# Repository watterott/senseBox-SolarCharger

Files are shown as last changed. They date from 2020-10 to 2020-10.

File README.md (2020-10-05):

# senseBox SolarCharger
SolarCharger extension for the senseBox MCU

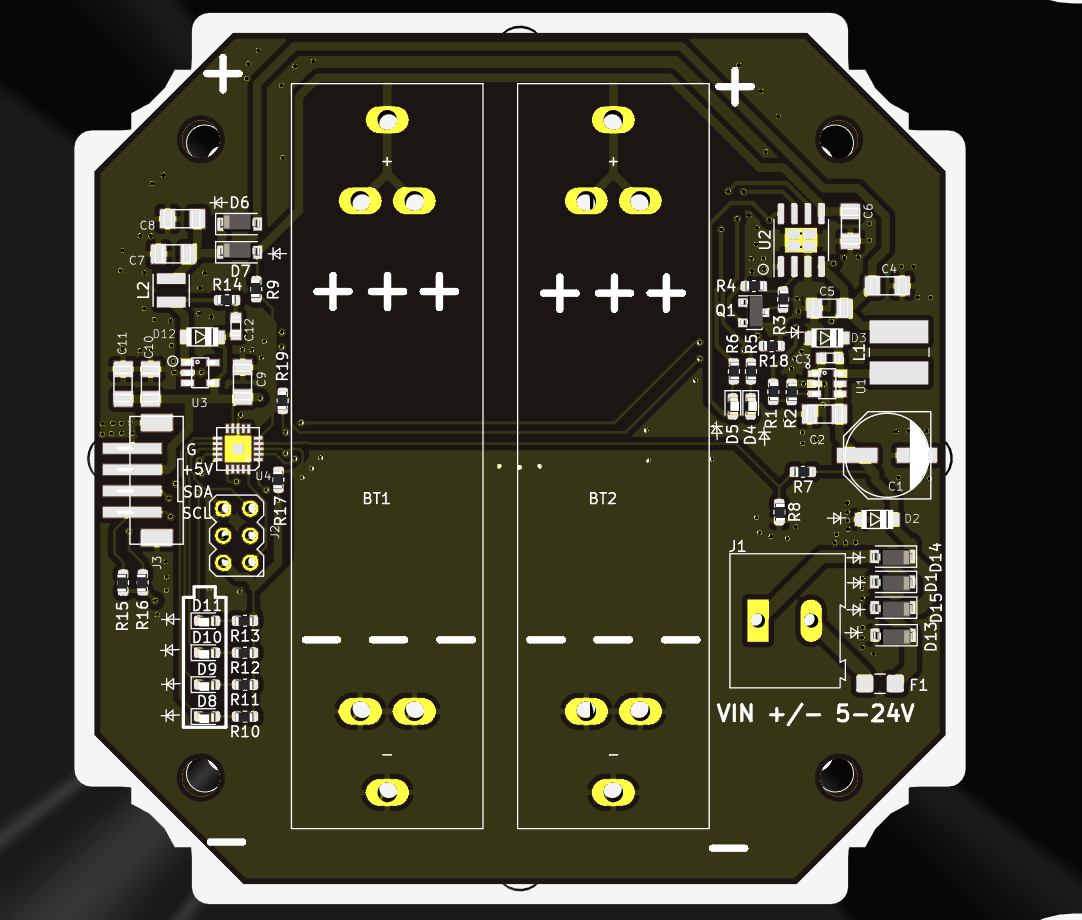
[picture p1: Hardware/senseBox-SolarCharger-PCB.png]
senseBox SolarCharger


* senseBox SolarCharger for up to 2x 18650 LiPo batteries
* 7-24V Solar input voltage
* Open-Source and released under the [Creative Commons Attribution Share-Alike License](https://creativecommons.org/licenses/by-sa/4.0/).
* **[Documentation on learn.watterott.com](https://learn.watterott.com)**

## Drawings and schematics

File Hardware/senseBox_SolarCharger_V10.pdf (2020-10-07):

10k | C10
100n | R19

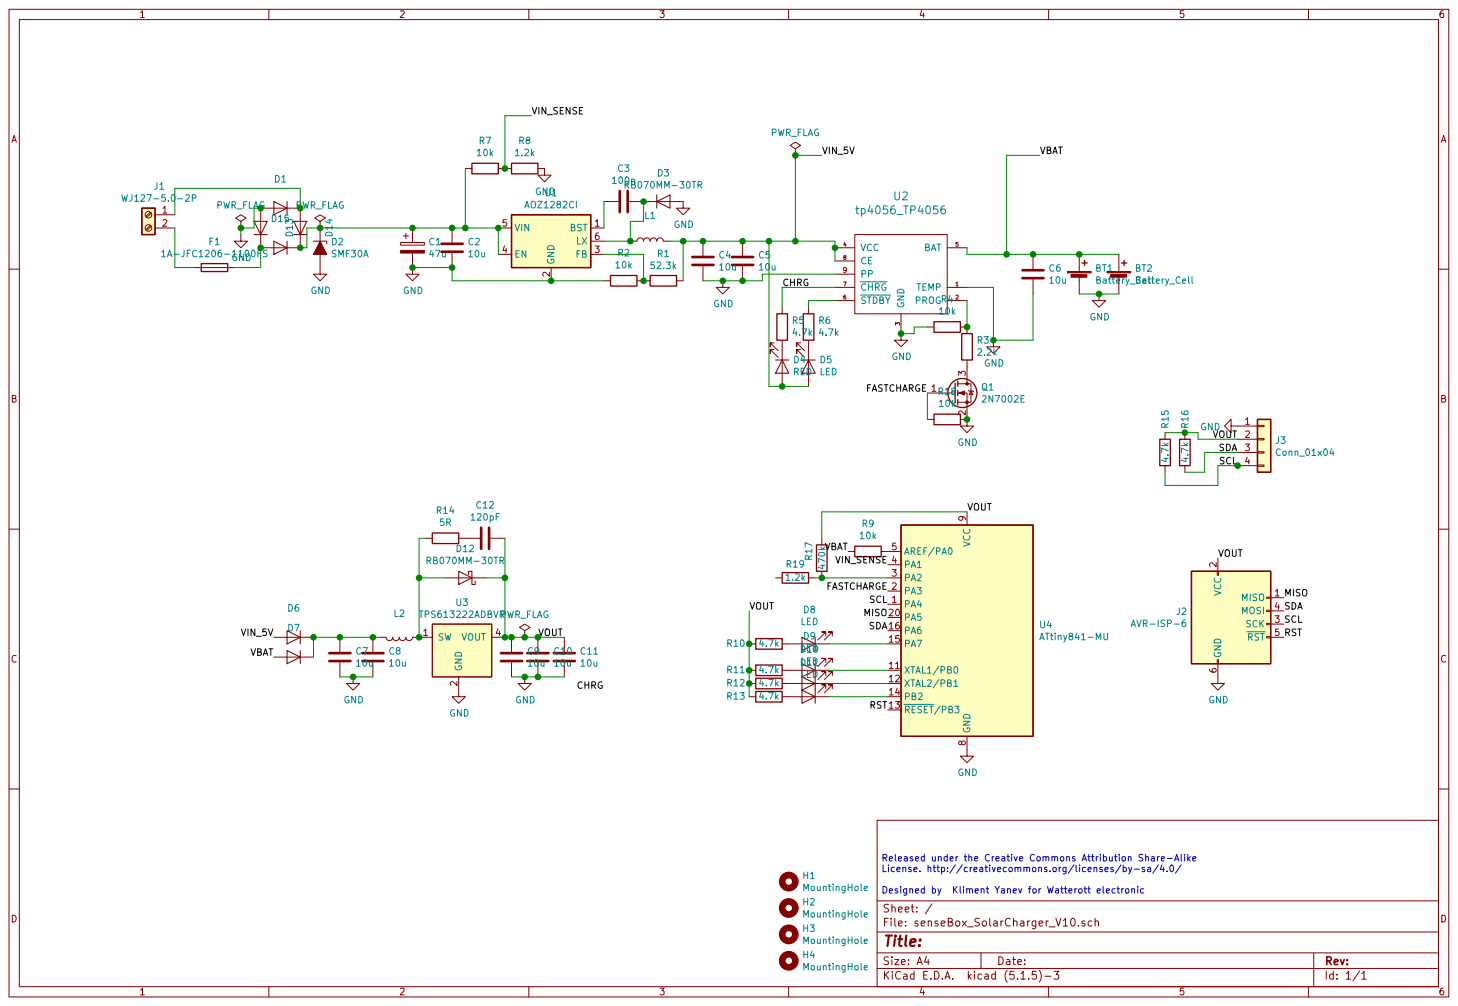
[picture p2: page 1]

3 VCC 4 BAT 5 STDBY 6 CHRG 7 CE 8 PP 9 U2

2 SCK 3 MOSI 4 RST 5 GND

Released under the Creative Commons Attribution Share-Alike License. http://creativecommons.org/licenses/by-sa/4.0/

Designed by Kliment Yanev for Watterott electronic
File: senseBox_SolarCharger_V10.sch Sheet: /
Id: 1/1 Title:

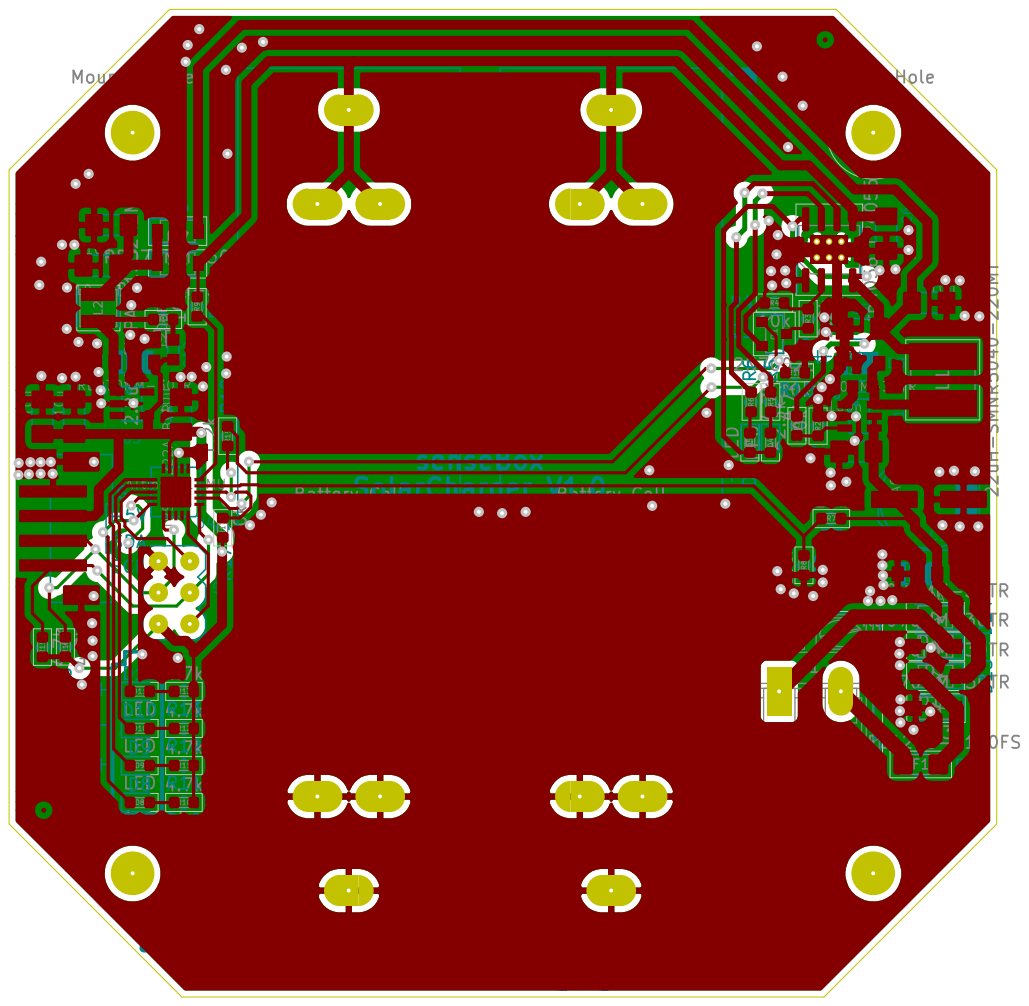
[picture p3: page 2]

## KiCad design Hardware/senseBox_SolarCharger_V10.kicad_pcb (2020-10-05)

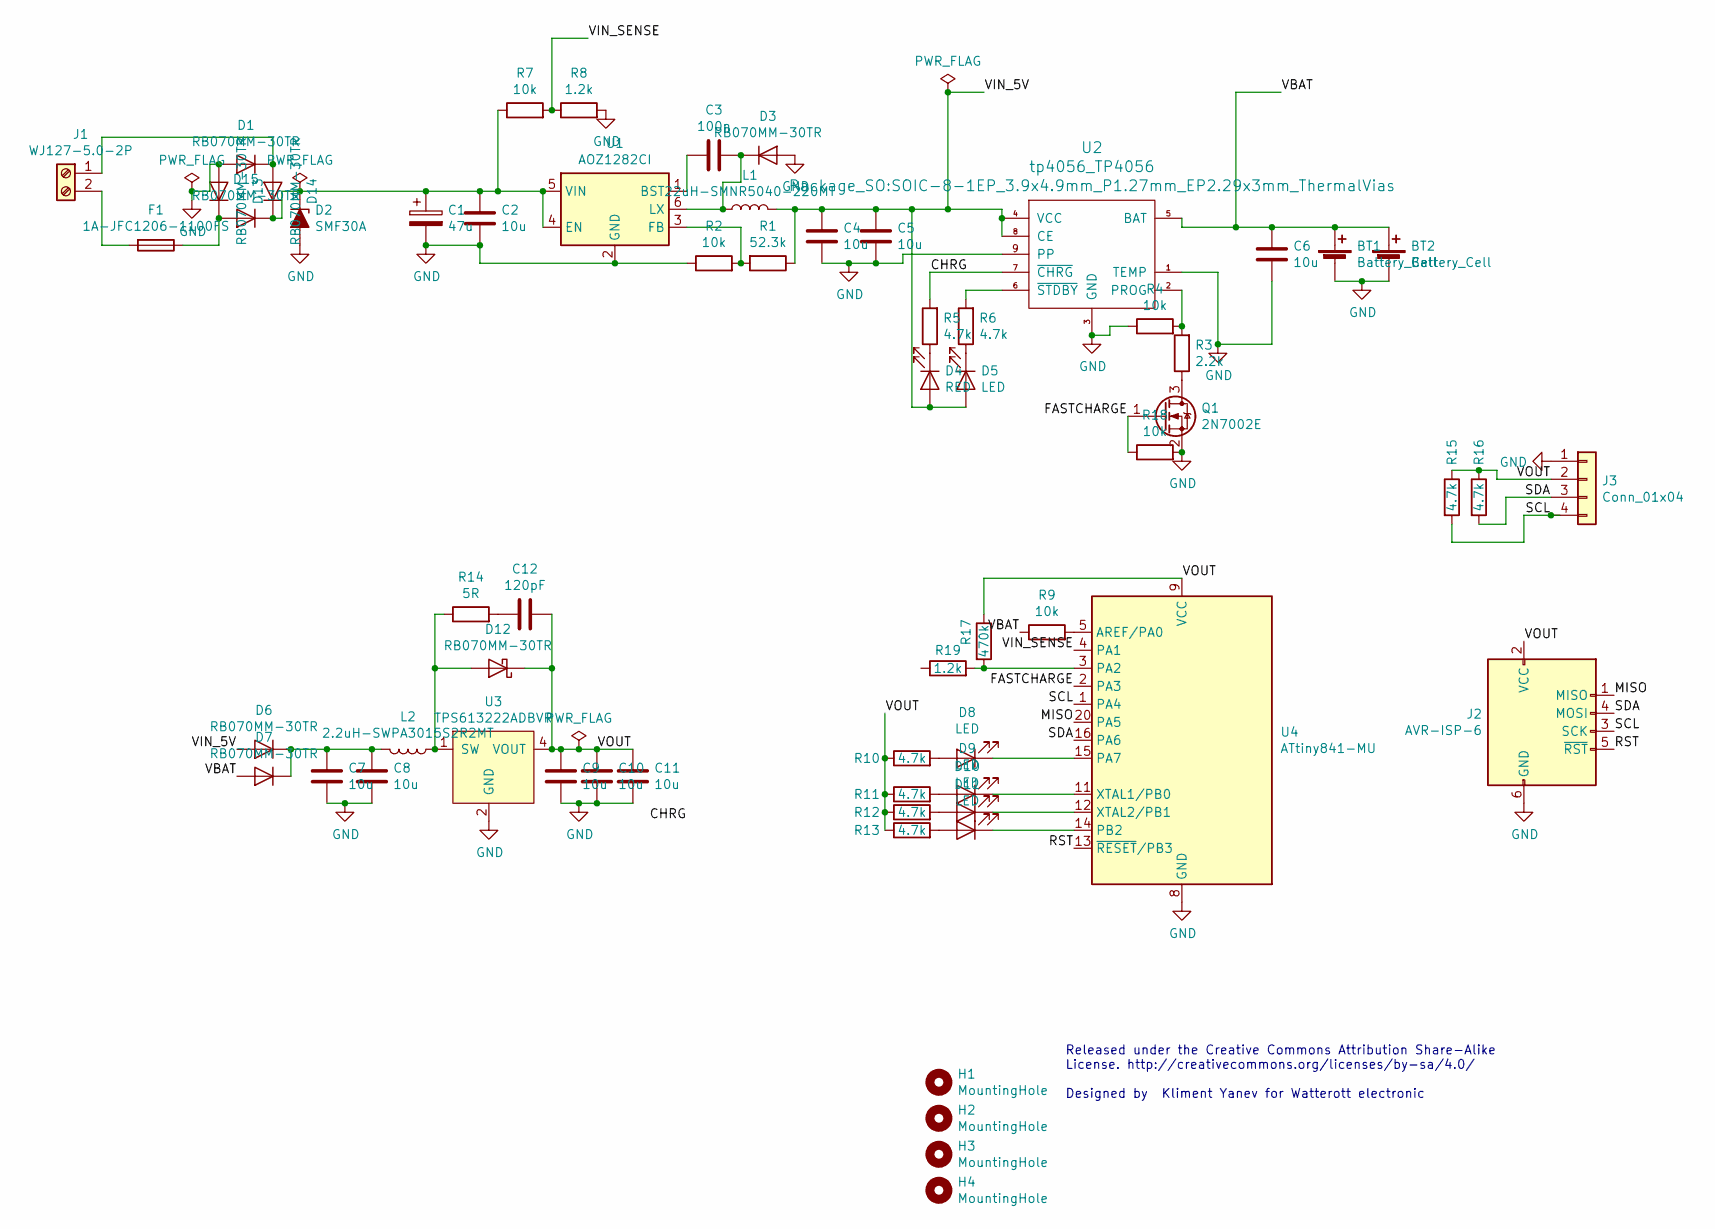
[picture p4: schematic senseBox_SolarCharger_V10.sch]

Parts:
BT1, BT2: Battery_Cell; Keystone-54x2-18650
C1: 47u; C_6.3MM
C2, C4, C5, C6, C7, C8, C9, C10, C11: 10u; C1206
C3: 100n; C0603
C12: 120pF; C0603
D1, D6, D7, D13, D14, D15: RB070MM-30TR; D_SOD-123
D2: SMF30A; SOD123
D3, D12: RB070MM-30TR; SOD123
D4: RED; LED_0603_1608Metric
D5, D8, D9, D10, D11: LED; LED_0603_1608Metric
F1: 1A-JFC1206-1100FS; Fuse_1206_3216Metric_Castellated
H1, H2, H3, H4: MountingHole; MountingHole_3.5mm
J1: WJ127-5.0-2P; TerminalBlock_Altech_AK300-2_P5.00mm
J2: AVR-ISP-6; MA03-2
J3: Conn_01x04; JST_B4B-PH-SM4-TB
L1: 22uH-SMNR5040-220MT; L_Wuerth_WE-PD2-Typ-MS
L2: 2.2uH-SWPA3015S2R2MT; L_Neosid_SMS-ME3010
Q1: 2N7002E; SOT-23
R1: 52.3k; R_0603_1608Metric
R2, R4, R7, R9, R18: 10k; R_0603_1608Metric
R3: 2.2k; R_0603_1608Metric
R5, R6, R10, R11, R12, R13, R15, R16: 4.7k; R_0603_1608Metric
R8, R19: 1.2k; R_0603_1608Metric
R14: 5R; R_0603_1608Metric
R17: 470k; R_0603_1608Metric
U1: AOZ1282CI; SOT23-6
U2: tp4056_TP4056; SOIC-8-1EP_3.9x4.9mm_P1.27mm_EP2.29x3mm_ThermalVias
U3: TPS613222ADBVR; SOT23-5
U4: ATtiny841-MU; QFN20-PAD

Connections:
/CHRG: R5.2, R19.1, U2.7 (~CHRG)
/FASTCHARGE: Q1.1 (G), R18.1, U4.2 (PA3)
/MISO: J2.1 (MISO), U4.20 (PA5)
/RST: J2.5 (~RST), U4.13 (~RESET~/PB3)
/SCL: J2.3 (SCK), J3.4, R15.2, U4.1 (PA4)
/SDA: J2.4 (MOSI), J3.3, R16.2, U4.16 (PA6)
/VBAT: BT1.1 (+), BT2.1 (+), C6.1, D7.2 (A), R9.1, U2.5 (BAT)
/VIN_5V: C4.1, C5.1, D4.2 (A), D5.2 (A), D6.2 (A), L1.2, R1.1, U2.4 (VCC), U2.8 (CE)
/VIN_SENSE: R7.2, R8.1, U4.4 (PA1)
/VOUT: C9.1, C10.1, C11.1, C12.1, D12.1 (K), J2.2 (VCC), J3.2, R10.1, R11.1, R12.1, R13.1, R15.1, R16.1, R17.1, U3.4 (VOUT), U4.9 (VCC)
GND: BT1.2 (-), BT2.2 (-), C1.2, C2.2, C4.2, C5.2, C6.2, C7.2, C8.2, C9.2, C10.2, C11.2, D1.2 (A), D2.2 (A), D3.2 (A), D13.2 (A), J2.6 (GND), J3.1, Q1.2 (S), R2.1, R4.1, R8.2, R18.2, U1.2 (GND), U2.1 (TEMP), U2.3 (GND), U2.9 (PP), U3.2 (GND), U4.8 (GND), U4.21 (GND)
unnamed: C1.1, C2.1, D2.1 (K), D14.1 (K), D15.1 (K), R7.1, U1.4 (EN), U1.5 (VIN)
unnamed: C3.1, D3.1 (K), L1.1, U1.6 (LX)
unnamed: C3.2, U1.1 (BST)
unnamed: C7.1, C8.1, D6.1 (K), D7.1 (K), L2.2
unnamed: C12.2, R14.2
unnamed: D1.1 (K), D14.2 (A), J1.1
unnamed: D4.1 (K), R5.1
unnamed: D5.1 (K), R6.1
unnamed: D8.1 (K), U4.15 (PA7)
unnamed: D8.2 (A), R10.2
unnamed: D9.1 (K), U4.11 (XTAL1/PB0)
unnamed: D9.2 (A), R11.2
unnamed: D10.1 (K), U4.12 (XTAL2/PB1)
unnamed: D10.2 (A), R12.2
unnamed: D11.1 (K), U4.14 (PB2)
unnamed: D11.2 (A), R13.2
unnamed: D12.2 (A), L2.1, R14.1, U3.1 (SW)
unnamed: D13.1 (K), D15.2 (A), F1.1
unnamed: F1.2, J1.2
unnamed: Q1.3 (D), R3.1
unnamed: R1.2, R2.2, U1.3 (FB)
unnamed: R3.2, R4.2, U2.2 (PROG)
unnamed: R6.2, U2.6 (~STDBY)
unnamed: R9.2, U4.5 (AREF/PA0)
unnamed: R17.2, R19.2, U4.3 (PA2)

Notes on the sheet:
Released under the Creative Commons Attribution Share-Alike License. http://creativecommons.org/licenses/by-sa/4.0/ Designed by Kliment Yanev for Watterott electronic

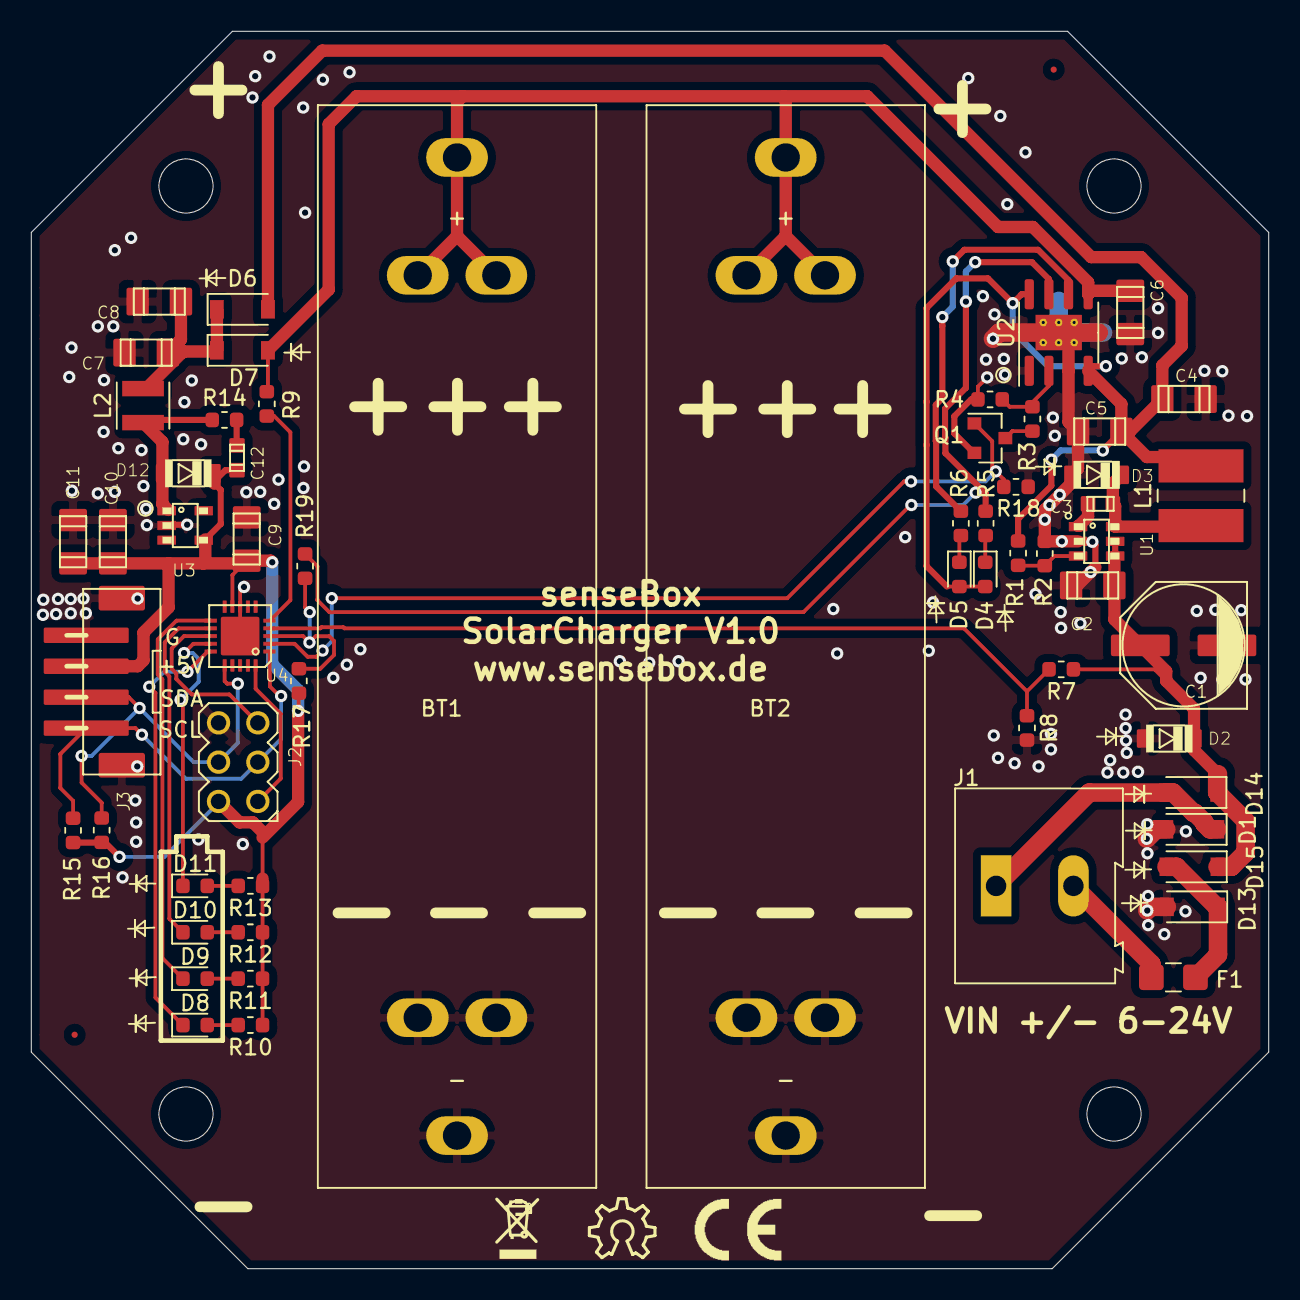
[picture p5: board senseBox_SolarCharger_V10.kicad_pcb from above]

Board: 2 copper layers, 80.0 x 80.0 mm, 63 parts (0 on the bottom side), 36 nets.

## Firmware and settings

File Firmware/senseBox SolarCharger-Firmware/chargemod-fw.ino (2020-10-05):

/*
 * Using ATtinycore, Attiny 841, No bootloader, 8MHz
 * 
 * 
 * Charge controller for sensebox power module. Functionalities:
 * Set PA3 to output low
 * Set PA2 to input, pullup
 * Set PA0, PA1, to analog input
 * Check temp, if temp above 12*C enable fast charge (PA3 high), 
 * if temp below 8*C disable fast charge (PA3 low)
 * Measure incoming voltage on PA1
 * Set PA7, PB0, PB1, PB2 to output high
 * Measure cell voltage on PA0
 * If cell voltage over 3.2V PA7 low
 * If cell voltage over 3.6V PB0 low
 * If cell voltage over 3.7V PB1 low
 * If cell voltage over 3.9V PB2 low
 * Check status for charge
 * Provide I2C i/f with following info:
 * - Register 0: cell voltage, 20mV/LSB
 * - Register 1: input voltage, 100mV/LSB
 * - Register 2: status bits: [B,I,L3,L2,L1,L0,F,C]
 *    B=battery present >2.8V<4.8V
 *    I=Input voltage present >4.5V
 *    L0-L3=battery status LEDs
 *    F=Fast charge enabled
 *    C=Charging
 * - Register 3: temperature in C, signed 8-bit

*/

#include <Wire.h>
#define SLAVE_ADDRESS 0x32
#define TEMP_OFFSET   275

volatile uint8_t i2creg[]={0x00,0x00,0x00,0x00};
volatile char i2cindex=0;

void setup() {
  // put your setup code here, to run once:
  pinMode(PA0, INPUT);
  pinMode(PA1, INPUT);
  pinMode(PA2, INPUT);
  pinMode(0, OUTPUT);
  pinMode(1, OUTPUT);
  pinMode(2, OUTPUT);
  pinMode(3, OUTPUT);
  pinMode(7, OUTPUT);
  digitalWrite(0,HIGH);
  digitalWrite(1,HIGH);
  digitalWrite(2,HIGH);
  digitalWrite(3,HIGH);
  digitalWrite(7,LOW);
  digitalWrite(PA2,HIGH);//pullup
  digitalWrite(PA0,LOW);//no pullup
  digitalWrite(PA1,LOW);//no pullup
  Wire.begin(SLAVE_ADDRESS);
  Wire.onRequest(requestEvent);
  Wire.onReceive(receiveEvent);
  
}

void loop() {
  uint8_t flags=0;
  // put your main code here, to run repeatedly:
  analogReference(INTERNAL1V1);
  analogRead(0x0C);
  delay(10);
  analogRead(0x0C);
  uint32_t temp_raw=analogRead(0x0C);
  int temp=(int)temp_raw-TEMP_OFFSET;
  i2creg[3]=temp;
  // 1LSB/C, calibrate if necessary

  analogReference(DEFAULT);
  analogRead(0x01);
  delay(10);
  int vin_raw=analogRead(0x01);
  //1024 LSBs, 5V VREF, 4.88mV/LSB
  //VIN is a 10k/1.2k voltage divider
  //VIN scaling factor is 9.3
  //vin_raw therefore has 4.88*9.3=45.54mV/LSB
  //we want vin in 100mV increments so we need to multiply by 0.45
  int vin=0.45*vin_raw;
  i2creg[1]=vin;
  if(vin>45){
    flags|=(1<<6);
  }else{
    flags&=~(1<<6);
  }
  
  //quick charge when warm enough and voltage >8V
  if(temp>=12 && temp<46 && vin>80){
    digitalWrite(7,HIGH);
    flags|=(1<<1);
  }
  if(temp<=8 || temp>50 || vin<80){
    digitalWrite(7,LOW);//hysteresis
    flags&=~(1<<1);
  }
  
  
  analogRead(0x00);
  uint32_t vbat_raw=analogRead(0x00);
  //1024 LSBs, 5V VREF, 4.88mV/LSB
  //we want vin in 20mV increments so we need to multiply by 0.244
  int vbat=0.244*vbat_raw;
  i2creg[0]=vbat;
  if(vbat>140 && vbat<240){
    flags|=(1<<7);
  }else{
    flags&=~(1<<7);
  }
  
  if(digitalRead(PA2)==LOW && vin>45 && vbat>140 && vbat <240){ //is battery charging - only possible if supply voltage high enough and battery present
    flags|=(1);
  }else{
    flags&=~(1);
  }
  
  
  if(vbat>160){
    digitalWrite(3,LOW);
    flags|=(1<<(2)); 
  }else{
    digitalWrite(3,HIGH);
    flags&=~(1<<(2)); 
  }
  if(vbat>180){
    digitalWrite(0,LOW);
    flags|=(1<<(3)); 
  }else{
    digitalWrite(0,HIGH);
    flags&=~(1<<(3)); 
  }
  if(vbat>185){
    digitalWrite(1,LOW);
    flags|=(1<<(4)); 
  }else{
    digitalWrite(1,HIGH);
    flags&=~(1<<(4)); 
  }
  if(vbat>195){
    digitalWrite(2,LOW);
    flags|=(1<<(5)); 
  }else{
    digitalWrite(2,HIGH);
    flags&=~(1<<(5)); 
  }
  i2creg[2]=flags;
  delay(100);
  
}

void receiveEvent()
{
  if(Wire.available()){
    i2cindex=Wire.read();
  }
}

void requestEvent()

{
     if(i2cindex>3)i2cindex=0;
     Wire.write(i2creg+i2cindex, 4-i2cindex);
     i2cindex=0;

}

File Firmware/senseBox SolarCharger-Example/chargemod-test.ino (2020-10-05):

/*
  SolarBox status

  Scans the I2C Bus for solarbox - address 0x32.
*/


/*
 * I2C i/f with following info on address 0x32:
 * - Register 0: cell voltage, 20mV/LSB
 * - Register 1: input voltage, 100mV/LSB
 * - Register 2: status bits: [B,I,L3,L2,L1,L0,F,C]
 *    B=battery present >2.8V
 *    I=Input voltage present >4.5V
 *    L0-L3=battery status LEDs
 *    F=Fast charge enabled
 *    C=Charging
 * - Register 3: temperature in C, signed 8-bit
 * Thresholds: L0: 3.2V, L1: 3.6V, L2: 3.7V, L3: 3.9V
 * Switch to slow charge at 8*C
 * Switch to fast charge at 12*C
*/
#include <Wire.h>
#include <senseBoxIO.h>

void setup()
{
  // init serial library
  Serial.begin(9600);
  while(!Serial); // wait for serial monitor
 
  // power on I2C ports
  senseBoxIO.powerI2C(true);

  // init I2C/Wire library
  Wire.begin();
}

void loop()
{
  byte devices, address;

  Serial.println("Scanning...");

  devices = 0;
  address=0x32;
  
    Wire.beginTransmission(address);
    byte error = Wire.endTransmission();
 
    if(error == 0)
    {
      devices++;
      Serial.print("Device found at 0x");
      Serial.println(address, HEX);
      
        Wire.requestFrom((uint8_t)address, (uint8_t)4);
        uint vbat=Wire.read();
        uint vin=Wire.read();
        uint flags=Wire.read();
        int temp=(int8_t)(Wire.read());
        Serial.println(String("Vbat:")+(20*vbat)+"mv");
        Serial.println(String("Vin:")+(100*vin)+"mv");
        Serial.print(String("Flags:"));
        Serial.println(flags,BIN);
        if(flags&1){
          Serial.println("Charging");
        }else{
          Serial.println("Not charging");
        }
        if(flags&2){
          Serial.println("Temperature normal");
        }else{
          Serial.println("Temperature cold - slow charge only");
        }
        if(flags&64){
          Serial.println("Input voltage sufficient to charge");
        }else{
          Serial.println("Input voltage too low");
        }
        if(flags&128){
          Serial.println("Battery present");
        }else{
          Serial.println("Battery missing");
        }
        Serial.print("Charge LEDs on: ");
        if(flags&4)Serial.print("1 ");
        if(flags&8)Serial.print("2 ");
        if(flags&16)Serial.print("3 ");
        if(flags&32)Serial.print("4 ");
        if((flags&(4|8|16|32))==0){
          Serial.println("None");
        }else{
          Serial.println();
        }
        
        Serial.println(String("temp:")+(temp)+"*C");
        
      
    }
    else if(error == 4)
    {
      Serial.print("Unknown error at 0x");
      Serial.println(address, HEX);
    }    
  
  
  if(devices == 0)
  {
    Serial.println("No devices found\n");
  }
  else
  {
    Serial.println("done\n");
  }

  delay(2000); // wait 2 seconds for next scan
}

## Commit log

2020-10-05 Add files via upload
    first commit
    [chargemod-hw-B_Cu.gbl, chargemod-hw-B_Mask.gbs, chargemod-hw-B_SilkS.gbo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]
2020-10-05 Add files via upload
    added PCB image
